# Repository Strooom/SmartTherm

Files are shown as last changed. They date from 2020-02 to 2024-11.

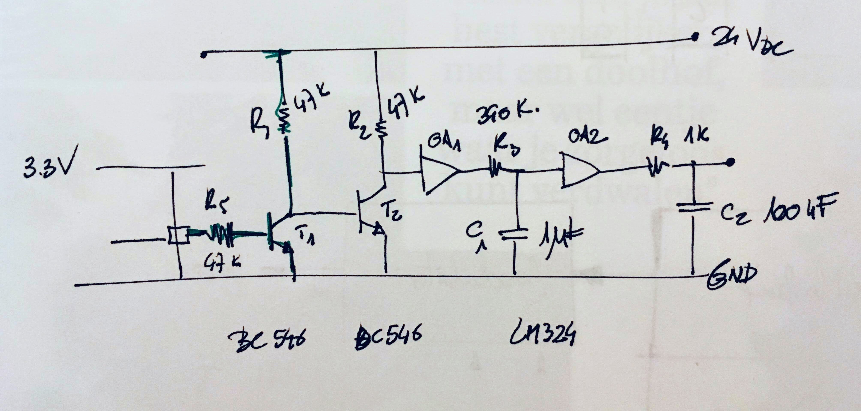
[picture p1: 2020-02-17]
docs/Schematics.JPG

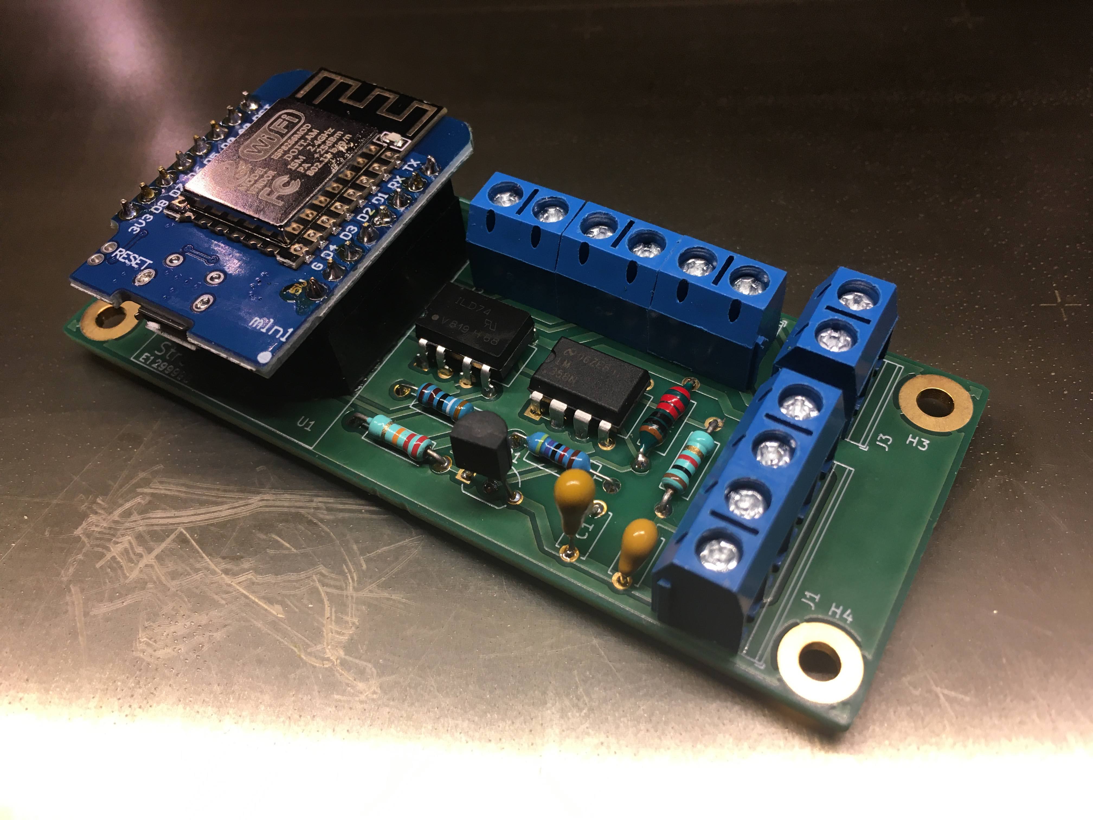
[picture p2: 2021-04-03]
docs/Hardware V2.JPG

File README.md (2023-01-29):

# SmartTherm
Controlling a Junkers heating (Eurostar ZWE24) with an IoT thermostat

* schematics (kiCAD)
* PCB (kiCAD)
* TouchScreen control (Nextion display)
* SmartPhone app (Blynk)
* 3D Printed enclosure (Fusion360)
* Alternative config with ESPHome and Home Assistant

All documentation is in the Wiki : https://github.com/Strooom/SmartTherm/wiki

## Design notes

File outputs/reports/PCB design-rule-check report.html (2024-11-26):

Logo

| DRC report for SmartTherm-PCB
| PCB: SmartTherm-PCB Revision: None Date: 2024-11-26T11:26:57+0000 KiCad Version: 8.0.6 | Errors: 0 Warnings: 0 Total: 0

Generated by KiBot (https://github.com/INTI-CMNB/KiBot/) v1.8.2

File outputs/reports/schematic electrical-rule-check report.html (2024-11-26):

Logo

| ERC report for SmartTherm-PCB
| Schematic: SmartTherm-PCB Revision: V3.0 Date: 2024-11-26T11:26:56+0000 KiCad Version: 8.0.6 | Errors: 0 Warnings: 0 Total: 0

Generated by KiBot (https://github.com/INTI-CMNB/KiBot/) v1.8.2

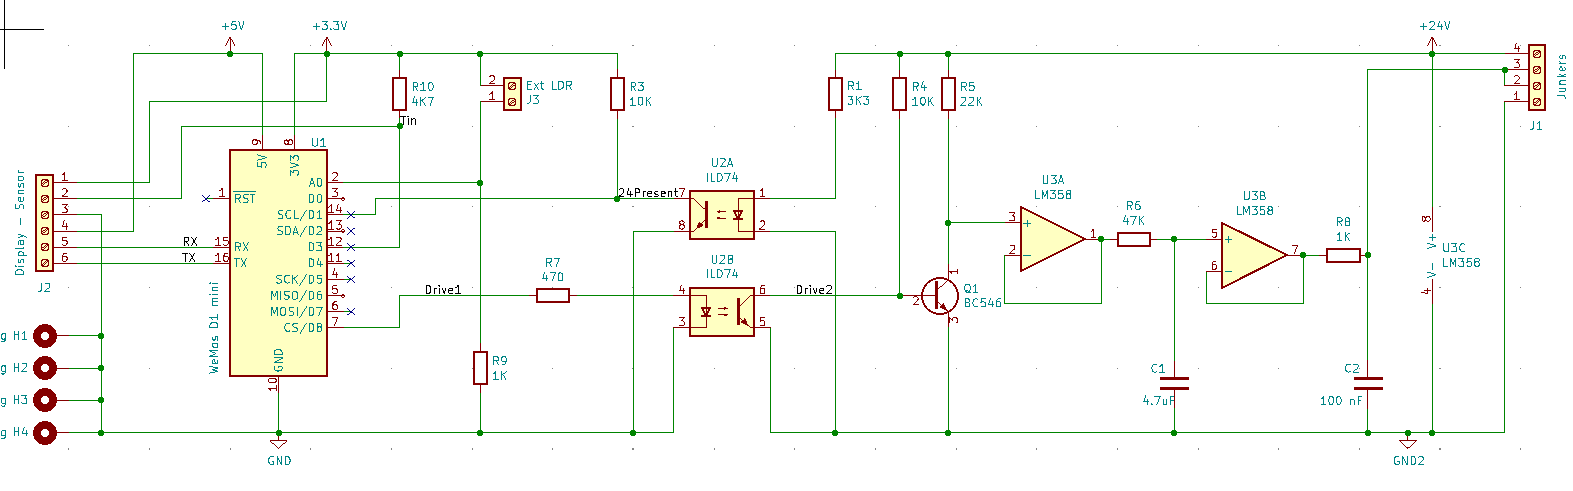
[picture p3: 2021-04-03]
docs/Schematics V2.PNG

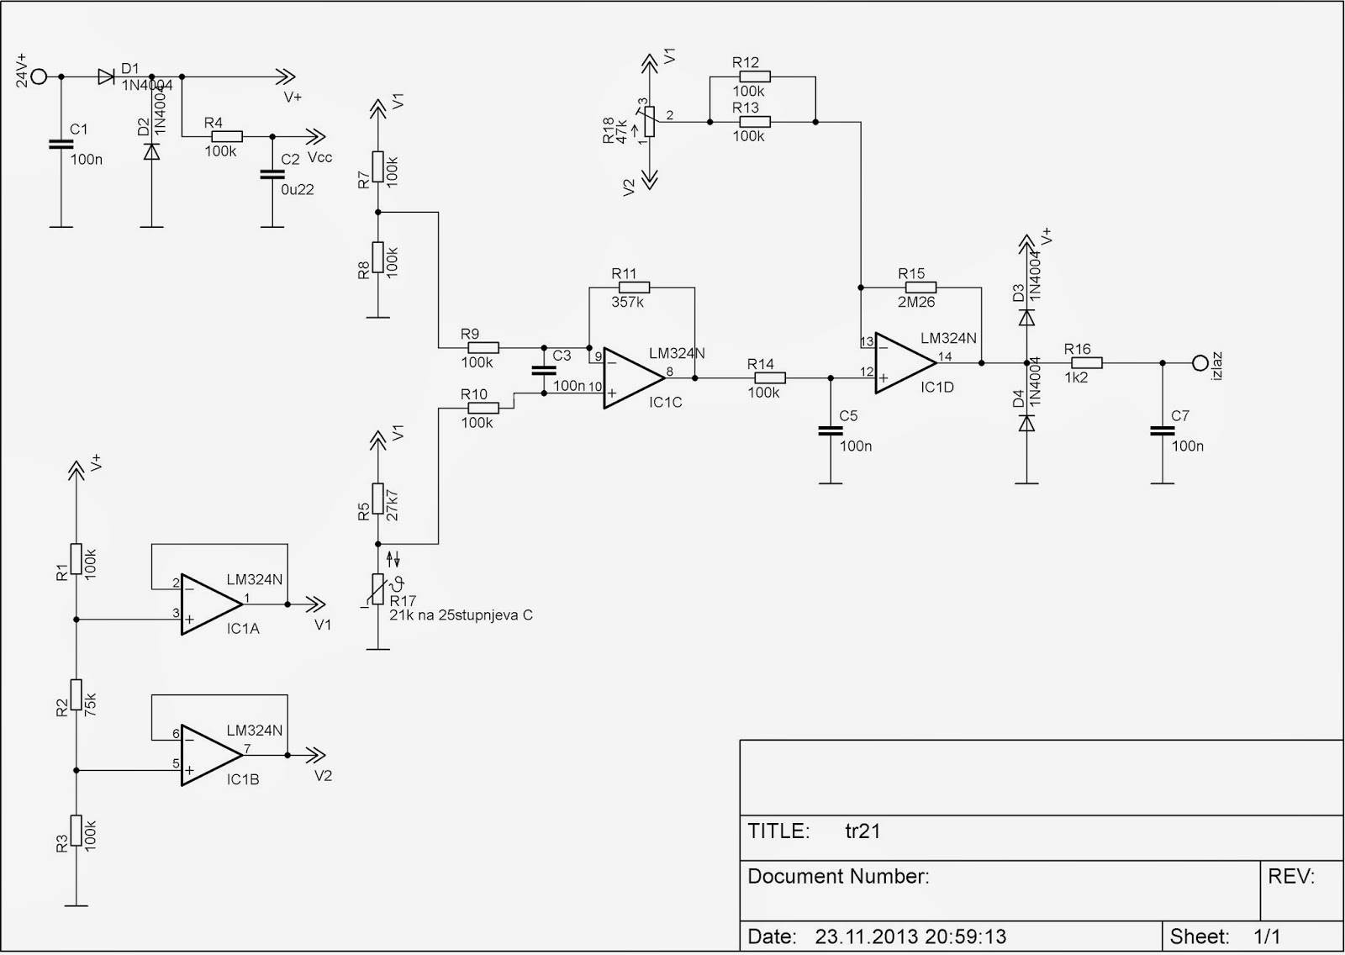
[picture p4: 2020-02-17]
docs/Schematics TR21.jpg

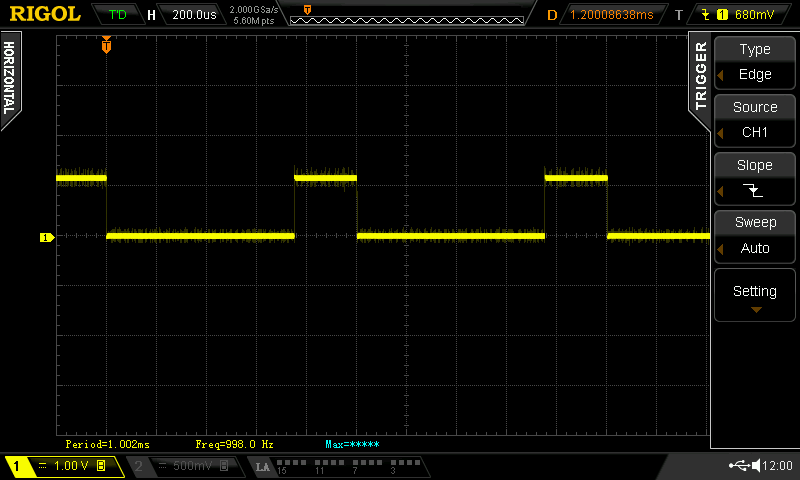
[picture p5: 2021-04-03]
docs/optocoupler input.png

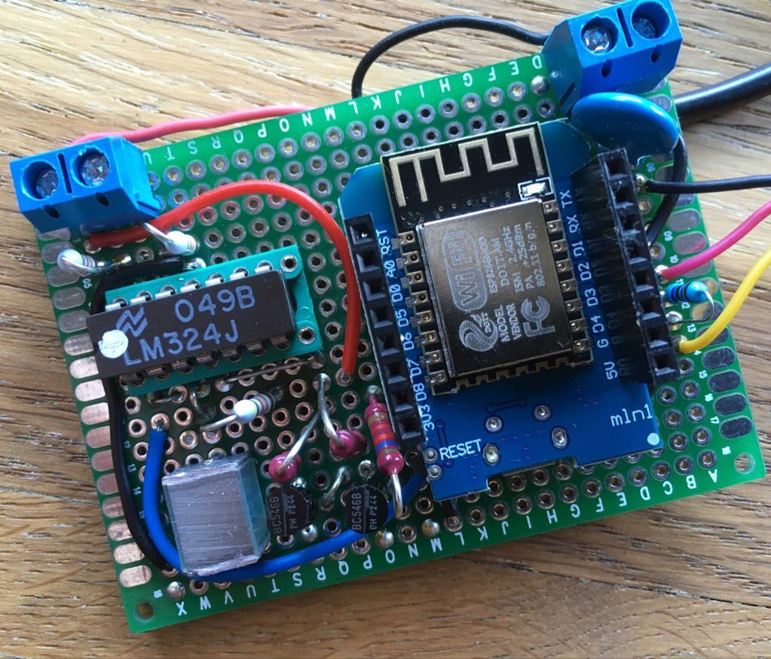
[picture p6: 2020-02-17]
docs/Prototype.JPG

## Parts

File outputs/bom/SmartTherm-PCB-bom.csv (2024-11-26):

Row | Description | Part | References | Value | Footprint | Quantity Per PCB | Status | Datasheet | manufacturerPartNumber | mouserPartNumber
1 |  | C | C2 | 100 nF | C_Disc_D4.7mm_W2.5mm_P5.00mm | 1 |  | https://product.tdk.com/system/files/dam/doc/product/capacitor/ceramic/lead-mlcc/catalog/leadmlcc_halogenfree_fa_en.pdf | FA22X7R2J104KNU06 | 810-FA22X7R2J104KNU6
2 |  | C | C1 | 4.7uF | C_Disc_D4.7mm_W2.5mm_P5.00mm | 1 |  | https://www.mouser.be/datasheet/2/281/1/RCE_X7R_X7S_25V_100V_E-1670872.pdf | RCEC72A475MWM1H03A | 81-RCEC72A475MWM1H3A
3 |  | Screw_Terminal_01x06 | J2 | Display - Sensor | TerminalBlock_Phoenix_PT-1,5-6-5.0-H_1x06_P5.00mm_Horizontal | 1 |  | https://www.phoenixcontact.com/us/products/1730052/pdf | 1730052 | 651-1730052
4 |  | Screw_Terminal_01x02 | J3 | Ext LDR | TerminalBlock_Phoenix_PT-1,5-2-5.0-H_1x02_P5.00mm_Horizontal | 1 |  | https://www.phoenixcontact.com/us/products/1711026/pdf | 1711026 | 651-1711026
5 |  | Screw_Terminal_01x04 | J1 | Junkers | TerminalBlock_Phoenix_PT-1,5-4-5.0-H_1x04_P5.00mm_Horizontal | 1 |  | https://www.phoenixcontact.com/us/products/1711042/pdf | 1711042 | 651-1711042
6 |  | BC546 | Q1 | BC546 | TO-92L_Inline_Wide | 1 |  | https://diotec.com/request/datasheet/bc546.pdf | BC546A | 637-BC546A
7 |  | R | R7 | 470 | R_Axial_DIN0207_L6.3mm_D2.5mm_P10.16mm_Horizontal | 1 |  | https://www.vishay.com/doc?31027 | RL07S471GB14 | 71-RL07S-G-470
8 |  | R | R8 R9 | 1K | R_Axial_DIN0207_L6.3mm_D2.5mm_P10.16mm_Horizontal | 2 |  | https://www.vishay.com/doc?31027 | RL07S102GB14 | 71-RL07S-G-1K
9 |  | R | R1 | 3K3 | R_Axial_DIN0207_L6.3mm_D2.5mm_P10.16mm_Horizontal | 1 |  | https://www.vishay.com/doc?31027 | RL07S332GB14 | 71-RL07S-G-3.3K
10 |  | R | R10 | 4K7 | R_Axial_DIN0207_L6.3mm_D2.5mm_P10.16mm_Horizontal | 1 |  | https://www.vishay.com/doc?31027 | RL07S472GB14 | 71-RL07S-G-4.7K
11 |  | R | R3 R4 | 10K | R_Axial_DIN0207_L6.3mm_D2.5mm_P10.16mm_Horizontal | 2 |  | https://www.vishay.com/doc?31027 | RL07S103GB14 | 71-RL07S-G-10K
12 |  | R | R5 | 22K | R_Axial_DIN0207_L6.3mm_D2.5mm_P10.16mm_Horizontal | 1 |  | https://www.vishay.com/doc?31027 | RL07S223GB14 | 71-RL07S-G-22K
13 |  | R | R6 | 47K | R_Axial_DIN0207_L6.3mm_D2.5mm_P10.16mm_Horizontal | 1 |  | https://www.vishay.com/doc?31027 | RL07S473GB14 | 71-RL07S-G-47K
14 |  | ILD74 | U2 | ILD74 | DIP-8_W7.62mm | 1 |  | https://www.vishay.com/doc?83640 | ILD74 | 782-ILD74
15 |  | LM358 | U3 | LM358 | DIP-8_W7.62mm | 1 |  | https://www.ti.com/lit/gpn/lm358-n | LM358N/NOPB | 926-LM358N/NOPB
16 |  | WeMos_D1_mini | U1 | WeMos D1 mini | WEMOS_D1_mini_light | 1 |  | https://wiki.wemos.cc/products:d1:d1_mini#documentation
Project info:
Schematic: | SmartTherm-PCB
Variant: | default
Revision: | V3.0
Date: | 2024-11-26
KiCad Version: | 8.0.6+1
Statistics:
Component Groups: | 16
Component Count: | 18
Fitted Components: | 18
Number of PCBs: | 1
Total Components: | 18

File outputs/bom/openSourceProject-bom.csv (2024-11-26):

Row | Description | Part | References | Value | Footprint | Quantity Per PCB | Status | Datasheet
1 | Light emitting diode | LED | D1 | LED | LED_0603_1608Metric | 1 |  | ~
2 | Resistor | R | R1 | R | R_0603_1608Metric | 1 |  | ~
Project info:
Schematic: | openSourceProject
Variant: | default
Revision: | V0.9
Date: | Tue Oct 15 12:13:48 2024
KiCad Version: | 8.0.4+1
Statistics:
Component Groups: | 2
Component Count: | 2
Fitted Components: | 2
Number of PCBs: | 1
Total Components: | 2

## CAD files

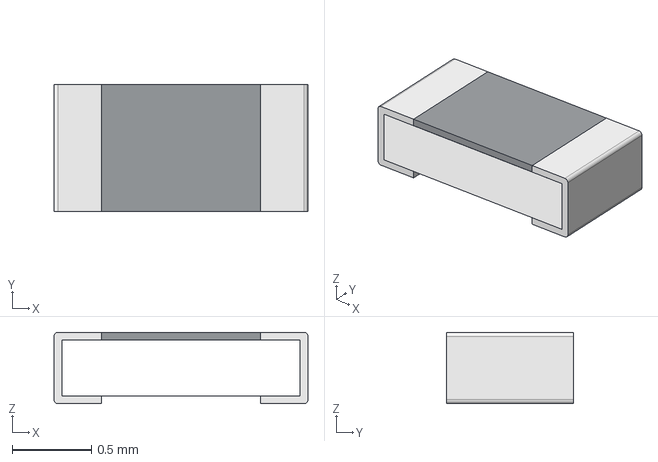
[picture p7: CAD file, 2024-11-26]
inputs/3dmodels/R0603.step
1.60 x 0.8 x 0.45 mm

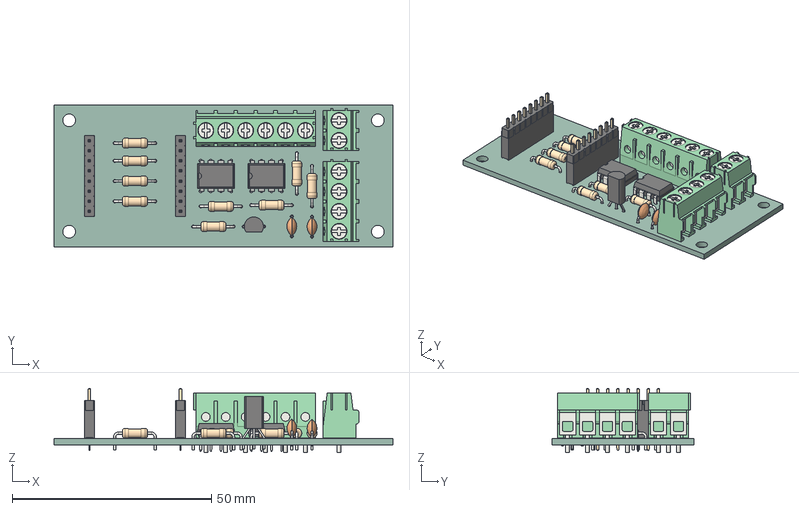
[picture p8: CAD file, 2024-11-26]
outputs/pcb/SmartTherm-PCB-3D.step
85.1 x 35.6 x 16.1 mm
C_Disc_D47mm_W25mm_P500mm x 2
TO-92L_Inline_Wide
R_Axial_DIN0207_L63mm_D25mm_P1016mm_Horizontal x 9
DIP-8_W7.62mm x 2
TerminalBlock_Phoenix_PT_15_2_50_H_1x02_P500mm_Horizontal
TerminalBlock_Phoenix_PT_15_4_50_H_1x04_P500mm_Horizontal
PinHeader_1x08_P254mm_Vertical x 2
PinSocket_1x08_P2.54mm_Vertical x 2
TerminalBlock_Phoenix_PT_15_6_50_H_1x06_P500mm_Horizontal
kibot_mradeprp_PCB

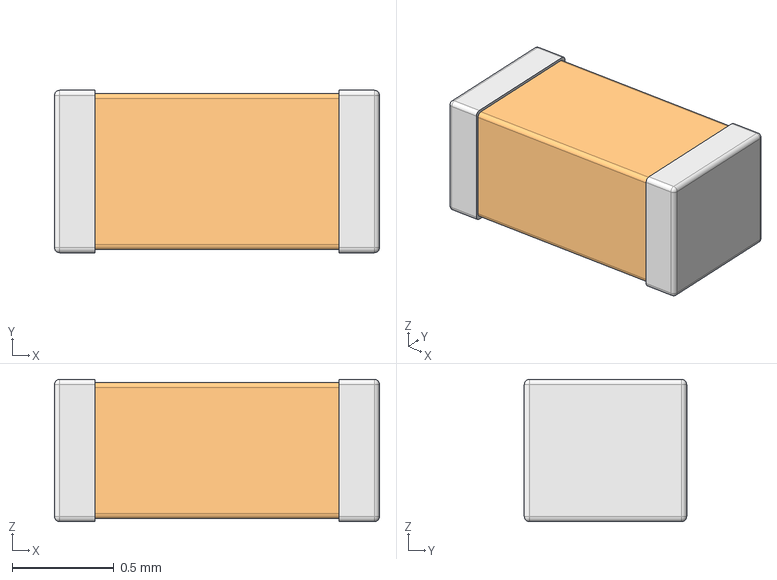
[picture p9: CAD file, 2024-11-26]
inputs/3dmodels/C0603.step
1.60 x 0.8 x 0.7 mm

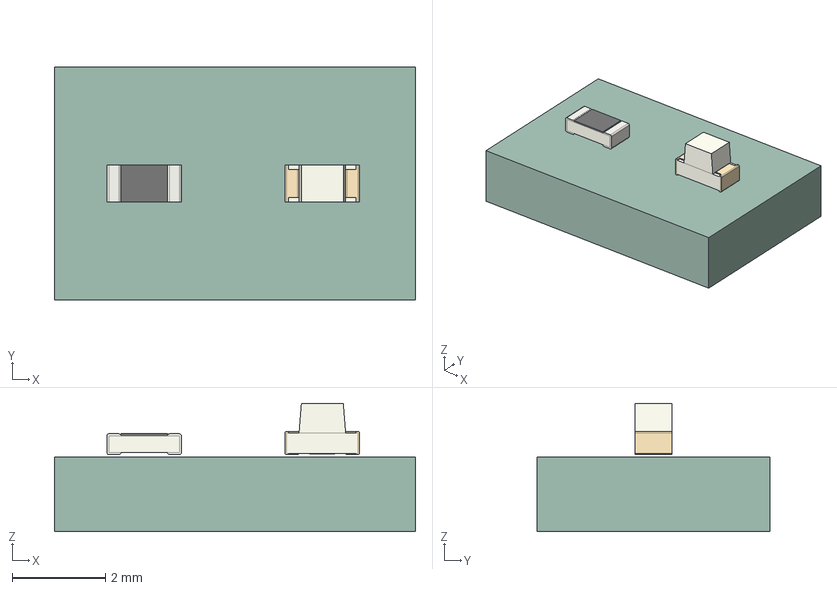
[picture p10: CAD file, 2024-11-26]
outputs/pcb/openSourceProject-3D.step
7.75 x 5.00 x 2.75 mm
LED_0603_1608Metric
R_0603_1608Metric
kibot_kx9a3z6y_PCB

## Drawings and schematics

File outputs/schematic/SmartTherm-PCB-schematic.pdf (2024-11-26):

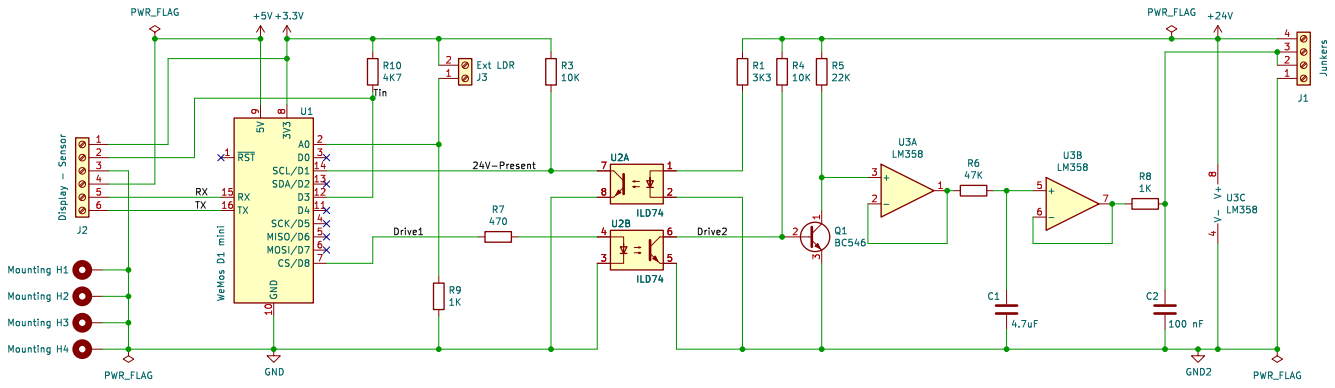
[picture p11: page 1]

File: SmartTherm-PCB.kicad_sch Sheet: / Strooom

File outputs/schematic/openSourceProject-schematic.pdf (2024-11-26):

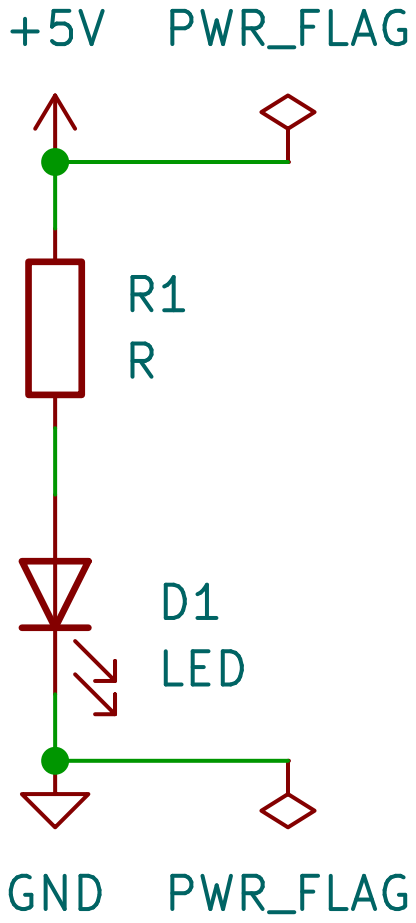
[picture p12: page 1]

Id: 1/1 Title: File: openSourceProject.kicad_sch Sheet: /

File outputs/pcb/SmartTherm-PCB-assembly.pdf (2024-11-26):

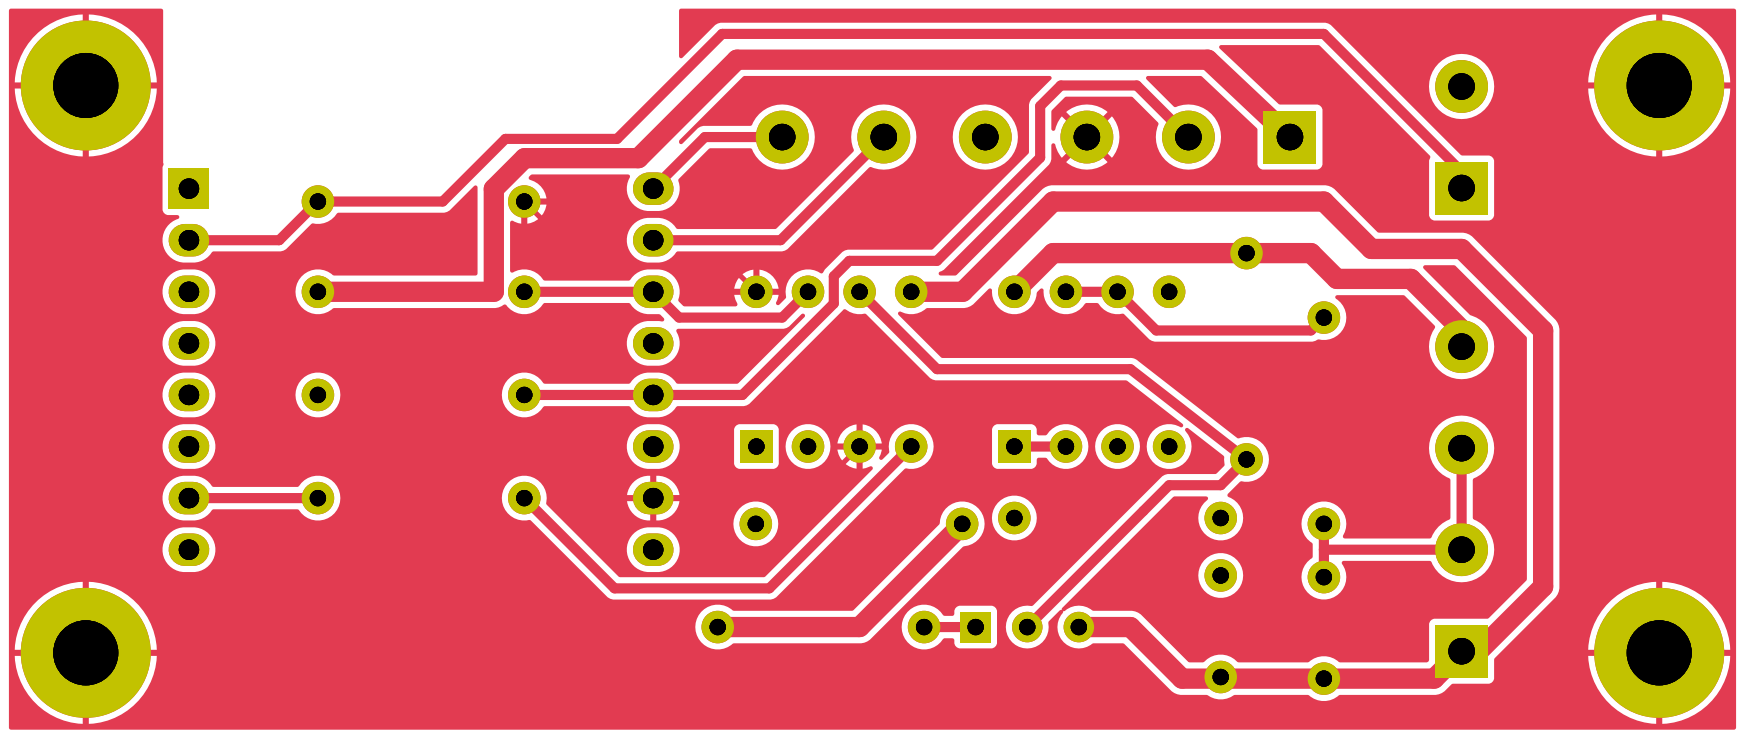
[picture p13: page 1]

U1

R7

SmartTherm V3.0
Strooom.be

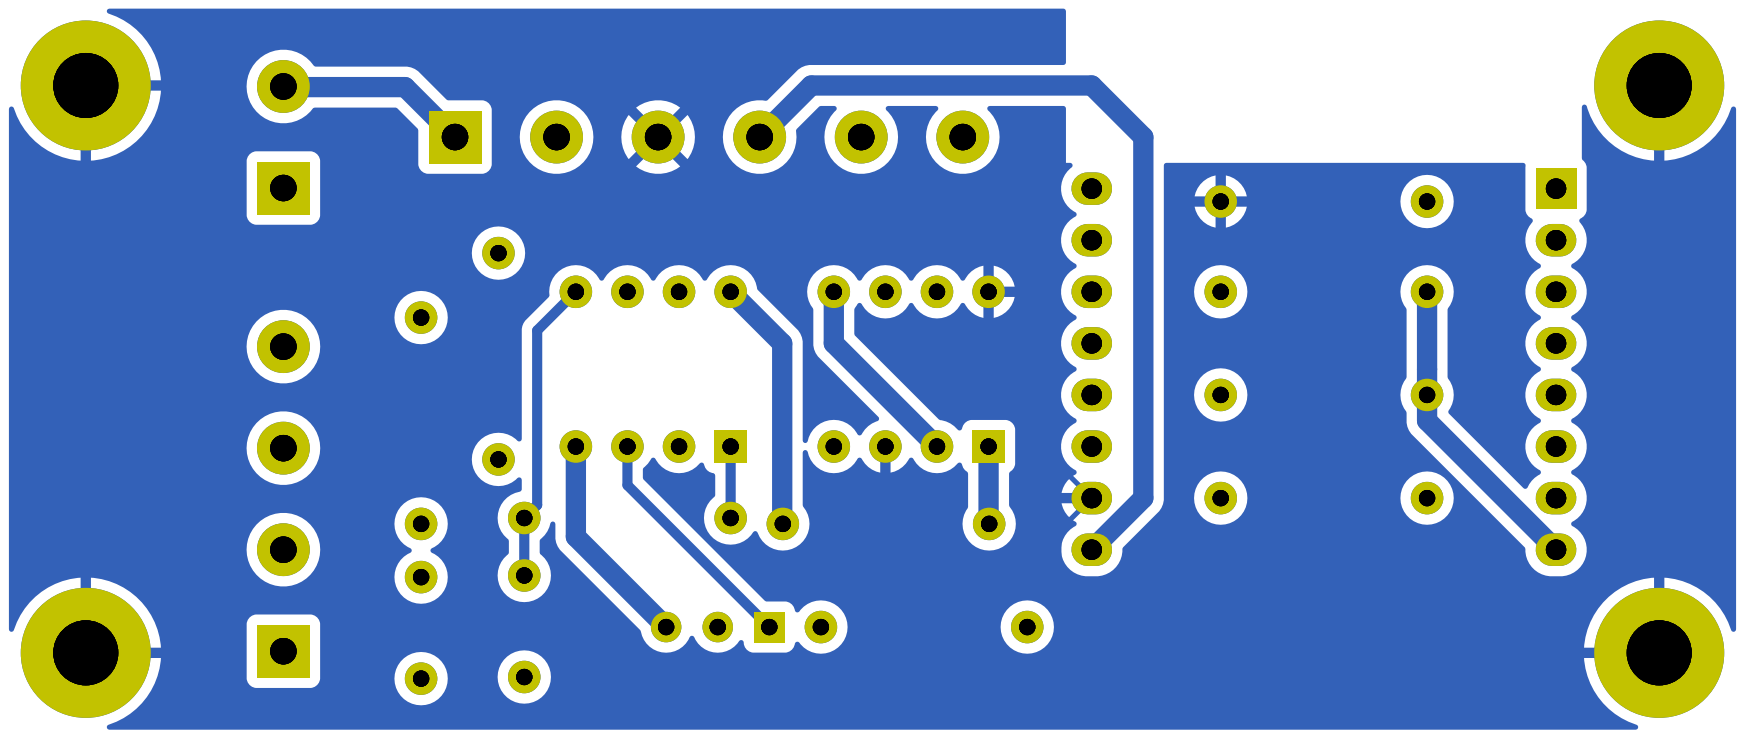
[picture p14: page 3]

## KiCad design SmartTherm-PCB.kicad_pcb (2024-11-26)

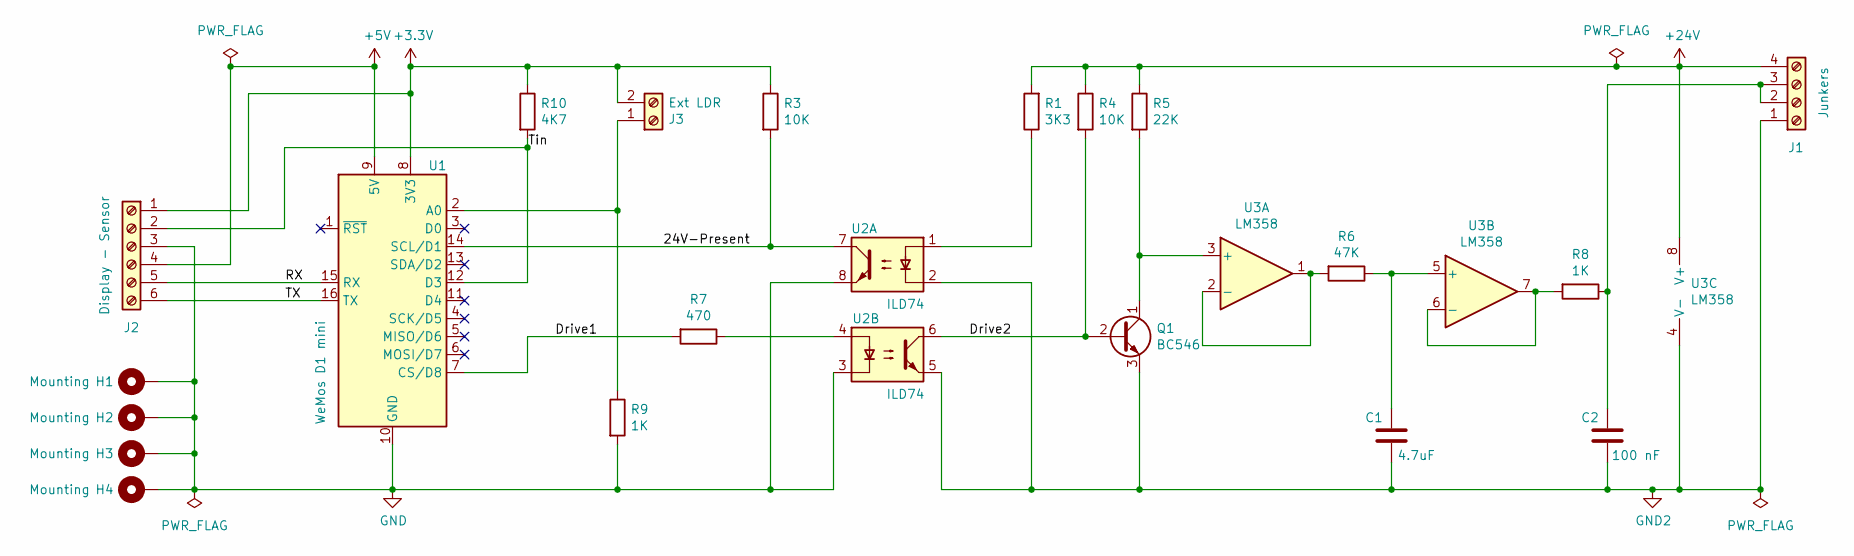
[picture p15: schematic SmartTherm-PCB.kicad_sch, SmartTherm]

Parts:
C1: 4.7uF; C_Disc_D4.7mm_W2.5mm_P5.00mm; manufacturerPartNumber RCEC72A475MWM1H03A; mouserPartNumber 81-RCEC72A475MWM1H3A
C2: 100 nF; C_Disc_D4.7mm_W2.5mm_P5.00mm; manufacturerPartNumber FA22X7R2J104KNU06; mouserPartNumber 810-FA22X7R2J104KNU6
H1, H2, H3, H4: Mounting; MountingHole_3.2mm_M3_Pad; manufacturerPartNumber na; mouserPartNumber na
J1: Junkers; TerminalBlock_Phoenix_PT-1,5-4-5.0-H_1x04_P5.00mm_Horizontal; manufacturerPartNumber 1711042; mouserPartNumber 651-1711042
J2: Display - Sensor; TerminalBlock_Phoenix_PT-1,5-6-5.0-H_1x06_P5.00mm_Horizontal; manufacturerPartNumber 1730052; mouserPartNumber 651-1730052
J3: Ext LDR; TerminalBlock_Phoenix_PT-1,5-2-5.0-H_1x02_P5.00mm_Horizontal; manufacturerPartNumber 1711026; mouserPartNumber 651-1711026
Q1: BC546; TO-92L_Inline_Wide; manufacturerPartNumber BC546A; mouserPartNumber 637-BC546A
R1: 3K3; R_Axial_DIN0207_L6.3mm_D2.5mm_P10.16mm_Horizontal; manufacturerPartNumber RL07S332GB14; mouserPartNumber 71-RL07S-G-3.3K
R3, R4: 10K; R_Axial_DIN0207_L6.3mm_D2.5mm_P10.16mm_Horizontal; manufacturerPartNumber RL07S103GB14; mouserPartNumber 71-RL07S-G-10K
R5: 22K; R_Axial_DIN0207_L6.3mm_D2.5mm_P10.16mm_Horizontal; manufacturerPartNumber RL07S223GB14; mouserPartNumber 71-RL07S-G-22K
R6: 47K; R_Axial_DIN0207_L6.3mm_D2.5mm_P10.16mm_Horizontal; manufacturerPartNumber RL07S473GB14; mouserPartNumber 71-RL07S-G-47K
R7: 470; R_Axial_DIN0207_L6.3mm_D2.5mm_P10.16mm_Horizontal; manufacturerPartNumber RL07S471GB14; mouserPartNumber 71-RL07S-G-470
R8, R9: 1K; R_Axial_DIN0207_L6.3mm_D2.5mm_P10.16mm_Horizontal; manufacturerPartNumber RL07S102GB14; mouserPartNumber 71-RL07S-G-1K
R10: 4K7; R_Axial_DIN0207_L6.3mm_D2.5mm_P10.16mm_Horizontal; manufacturerPartNumber RL07S472GB14; mouserPartNumber 71-RL07S-G-4.7K
U1: WeMos D1 mini; WEMOS_D1_mini_light
U2: ILD74; DIP-8_W7.62mm; manufacturerPartNumber ILD74; mouserPartNumber 782-ILD74
U3: LM358; DIP-8_W7.62mm; manufacturerPartNumber LM358N/NOPB; mouserPartNumber 926-LM358N/NOPB

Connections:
+3.3V: J2.1, J3.2, R3.1, R10.1, U1.8 (3V3)
+5V: J2.4, U1.9 (5V)
+24V: J1.4, R1.2, R4.1, R5.1, U3.8 (V+)
/24V-Present: R3.2, U1.14 (SCL/D1), U2.7
/Drive1: R7.2, U1.7 (CS/D8)
/Drive2: Q1.2 (B), R4.2, U2.6
/RX: J2.5, U1.15 (RX)
/TX: J2.6, U1.16 (TX)
/Tin: J2.2, R10.2, U1.12 (D3)
GND: H1.1, H2.1, H3.1, H4.1, J2.3, R9.2, U1.10 (GND), U2.3, U2.8
GND2: C1.2, C2.2, J1.1, Q1.3 (E), U2.2, U2.5, U3.4 (V-)
unnamed: C2.1, J1.2, J1.3, R8.1
unnamed: J3.1, R9.1, U1.2 (A0)
unnamed: Q1.1 (C), R5.2, U3.3 (+)
unnamed: R1.1, U2.1
unnamed: R7.1, U2.4
unnamed: R6.2, U3.1, U3.2 (-)
unnamed: C1.1, R6.1, U3.5 (+)
unnamed: R8.2, U3.6 (-), U3.7

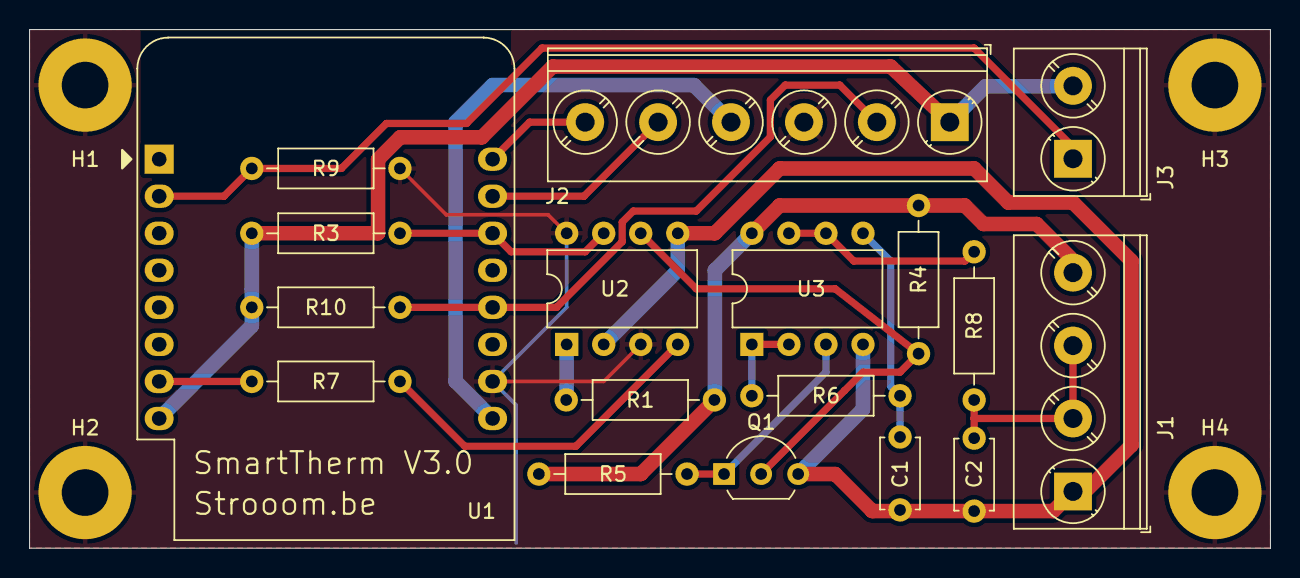
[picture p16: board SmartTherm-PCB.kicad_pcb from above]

Board: 2 copper layers, 85.1 x 35.6 mm, 22 parts (0 on the bottom side), 19 nets.

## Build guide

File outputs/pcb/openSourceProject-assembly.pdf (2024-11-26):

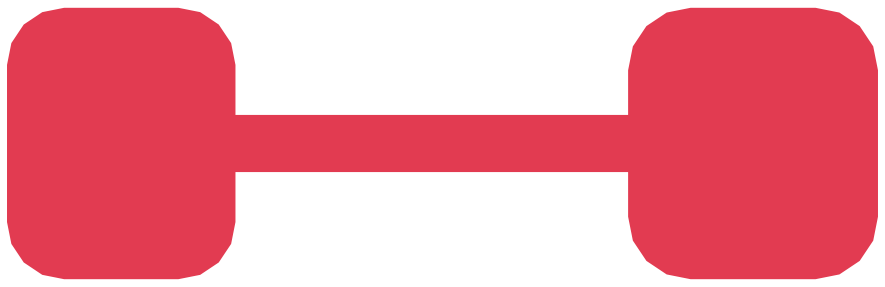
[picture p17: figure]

V0.9

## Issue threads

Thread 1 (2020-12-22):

Pic

mbrevda, 2020-12-22:
Can you possible show a picture of how this is connected to the boiler? Thanks!

Strooom, 2020-12-24:
Pin 1 = 24V
Pin 2 = Control : From thermostat or MCU to Junkers
Pin 4 = Ground

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

mbrevda, 2021-02-23:
Thanks! Ended up going with a Shelly as illustrated [here](https://blog.pattyland.de/2019/12/01/alte-junkers-gastherme-smart-machen/), along with thermostats in every room. I guess that means I'm not utilizing modulation. Wonder what the real-world implications are...

nagyrobi, 2023-11-13:
> Wonder what the real-world implications are...

Less efficiency thus higher energy consumption...

Closed 2020-12-24.

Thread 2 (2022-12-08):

Purchase options?

jkl83, 2022-12-08:
Hi,
I have Eurostar ZWE24 and wanted to control it through home assistant.
Is there any way you can help with that?

Can I buy your thermostat as a complete unit?

Thank you.

renarena, 2022-12-09:
i am also interested

Strooom, 2022-12-13:
Hi, if there would be sufficient demand, I could run a small production. However for 2 units it's not really profitable. Would need to be at least 20.. I'll keep your request in mind for the future.
On the ESP, you could connect MQTT to eg. a nodeRED and then from there you could connect ti to home assistant.

jensweimann, 2023-01-20:
Thank you very much for the work @Strooom!

I built the project recently and have a couple of spare pcbs that I ordered from pcbway. I'll send them inside germany if someone wants it. I can also share the list of components I purchased from an electronics shop.

Also I wrote a small esphome script for home assitant control. I can make a pull request for that if you're interested.

renarena, 2023-01-21:
I am interested. How can i contact you?

niesamowitysmyk, 2023-01-21:
I am intersting too. It is very intersting poject!

jensweimann, 2023-01-21:
Please send me a pm over here: https://community.home-assistant.io/t/control-junkers-gas-heating-1-2-4-interface-with-home-assistant/354658/7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

mtaberna, 2023-01-25:
I would also be interested @jensweimann

jensweimann, 2023-01-28:
See PR: https://github.com/Strooom/SmartTherm/pull/4

niesamowitysmyk, 2023-02-06:
I just launched this solution with my Junkers Eurostar. Everything started up perfectly, including the thermostat in the HA. Thank you very much!
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

Strooom, 2023-02-07:
Nice work!
I am now busy on some other projects (https://github.com/Strooom/MuMo-V2-Node-PCB for HW and https://github.com/Strooom/STM32WLE5x-SX126X-LoRa for the related firmware), so I am not actively working on this SmartTherm project at this time.
Still, it's always nice to read that a maker, somewhere in the world, found your work useful and helpful.
Note that I do have github sponsoring set up : https://github.com/sponsors/Strooom but a simple thank you is also appreciated.

Thank you all, good luck with your builds and have a nice day.

Tylkopoco, 2023-04-02:
> I just launched this solution with my Junkers Eurostar. Everything started up perfectly, including the thermostat in the HA. Thank you very much! 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

Do you have any PCBs left ?

jkl83, 2023-11-15:
Finished creating mine yesterday. Time to launch.
Got pcb from pcbway.com (had to get 5) very cheap as this was my first order.
Got all the components from tme.eu, but you can get those anywhere.

Thank you @Strooom and all other contributors.

nagyrobi, 2023-11-15:
Me too. I plan to sell 3 of them (assembled ready to run), keep one alive and one for spare.

Schnoop, 2023-11-16:
I made a list of the need components at my favourite electronic dealer: https://www.reichelt.de/my/2099518

nagyrobi, 2023-11-16:
Instead of direct screw terminals from the family CTB0502-6, I suggest to use family KFG-2EDGV-5.08-6P + KFG-2EDGK-5.08-6P, as they can be easily plugged/unplugged without having to re-screw cables.

Schnoop, 2023-11-16:
Yeah. Maybe an option. :)

Schnoop, 2023-11-28:
I ordered a few boards. I would give away five of these. Shipping only in Germany. 2.5 EUR via PayPal. The boards are not yet populated with components.

phmllr, 2024-01-30:
I Got 2 Completed PCBs with components sdolderd an 3 PCBs without components for sale if somone interested

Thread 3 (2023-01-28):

MQTT

fir3drag0n, 2023-01-28:
Is there a new firmware for v2 to control it by MQTT?

I would like to integrate it in iobroker.

jensweimann, 2023-01-28:
See PR: https://github.com/Strooom/SmartTherm/pull/4

Strooom, 2023-01-29:
I am currently not working on this project - feel free to build the hardware and put whatever ESP8266 (or even ESP32) software on it. For my application, it is doing its job and I have too many other developments taking up all of my time.

That being said : my original development is using Blynk, but this application has had a complete makeover, so the one I am using is obsolete. So, some day I could rewrite the software to work with some other cloud solution, eg the Arduino cloud.

Any developers interested on taking the development further : I can add you to the team and then you can take ownership.

Thank you all!

Closed 2023-01-29.

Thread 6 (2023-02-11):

add to description, how to connect  J1 to Junkers 1-2-4 interface

renarena, 2023-02-11:
Please, can you add the junkers 1-2-4 contacts in https://github.com/Strooom/SmartTherm/blob/master/hardware/SmartTherm-v2-schematics.pdf or add a note in the docs
to show J1 contacts 1 2 3 4 does not correspond to Junkers 1-2-4?

J1-1 = GND = Junkers 4
J1-4 = +24V = Junkers 1

Strooom, 2023-02-20:
You are right - it would have been better if the numbering on the SmartTherm connector was matching the numbering on the Junkers boilers. I will correct that in the next version.

In the mean time, here are the correct pin numberings on both sides:
Junkers 1 = 24V = SmartTherm 4
Junkers 2 = drive signal = SmartTherm 2 & 3
Junkers 4 = GND = SmartTherm 1

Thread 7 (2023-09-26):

junkers ZWB 24-1 DE

heapxor, 2023-09-26:
Hello there,
 I am also interested in that solution (reason why - https://community.home-assistant.io/t/bosch-gas-condensing-compact-heating-center-how-to-control-the-flat-heating).

Is that solution still working fine? Do i need to create a PCB by myself?

I am not sure what's 1-2-4 interface, my Junker heater comes with some PCB interface, where original CR 100 thermostat is plugged, i think its 24V circuit using modulation?

Also is there some extension to that solution with a valves, ie. each room separate thermostat (to capture temp) and its valve that is controlled by solution?

Appreciate your help!
Thanks for a great project.

niesamowitysmyk, 2023-09-26:
This solution works perfectly.
In project you can find pcb project files and place order for example in "pcbway" or others provider.
For control external rooms you need to find other independent solution - for example smart valves

heapxor, 2023-09-29:
@niesamowitysmyk thank you for the confirmation.
I do still miss the high level picture...

That project controls the heater using modulation. Assuming the pcb has its own temperature sensor?
So in case i want to extend solution to be able to read temp in multiple rooms and control temp in different rooms using electrical valves i somehow needs to - redesign it?

Maybe i am wrong and that project doesn't act like a room temp meter, and we need to send Temperature data to it ... ie it only turn on/off heater using modulation based on the input temperature value.

thanks

Strooom, 2023-09-29:
A DS18B20 temperature sensor is to be connected to the board. This is where the software gets the temperature. This kind of sensor allows several sensors to be connected to the same bus. But the maximal length of the wires is about 1 meter, so not enough to run to different rooms.

This design was never intended for controlling multiple rooms, and I think it would be too far off to adjust or tweak it.

nagyrobi, 2023-10-17:
I run about 25 DS18B20 sensor all around the house + one out in the yard at 50m distance. They are all connected in parallel, using a 1k resistor as pullup. Works flawlessly.

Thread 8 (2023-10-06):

esphome - smarttherm_power_level // and parallel use

phmllr, 2023-10-06:
esphome:
as seen in your esphome HomeAssistant integration there is an slider for configure the power level. This power level has to bee configured manually, right? So if there are 10°C in my room and i want it to be 20° i should make it to 100% until i reached the 20°C in x-minutes. But if the power level is only put to 50% it would need 2 times as long as on 100%. Did i understand that correctly?

Parallel use:
in some other projects i've seen some schematics with an diode put on the "Junkers 2" or on the J1-2&3 in your yousecase. The diode is for an parallel use of the original Junkers thermostat as backup in case of an broken esp or smotething else. is it possible to put the diodes in your schematics too? I would do by my self but i want t know if its possible with your hardware.

nagyrobi, 2023-11-04:
Have a look at the [PID Thermostat](https://esphome.io/components/climate/pid.html), which continuously adjusts the "slider" to keep temperature in your house.

jensweimann, 2023-11-15:
Personally on my setup the slider is controlled by home assistant automation, based on the delta between current temperature and target temperature. You can decide that way yourself what the appropriate power level is.

I came to the conclusion that its more economical to run the burner on minimal power for longer if possible.

nagyrobi, 2023-11-15:
@jensweimann what's the percentage of your burner during this minimal period? (I use bbqees's hardware to query boiler parameters).

jensweimann, 2023-11-15:
> @jensweimann what's the percentage of your burner during this minimal period? (I use bbqees's hardware to query boiler parameters).

I don't know about this hardware. I just set the slider to 1% which results in the minimal voltage that my burner accepts for powering on (8V).

> Is the automation you use the same as the one in this repo? I tested it, and find the power level calculated from the delta too small to heat up the house.

Yes. Well I guess the usage varies quite a bit for everyone so there is no right and wrong. We can only provide examples. Maybe you can also provide your solution with the PID Thermostat?

nagyrobi, 2023-11-15:
Does your heater have a small glass window you can peek in to see the gas burning? Do yo see the flame sizes? How big are they (maybe you can take a photo)?

My heater is a Junkers Ceraclass Excellence ZSC 28-3 MFA E 23, and it seems that this unit has a wider control range than your suggested 8V-15V interval. I created a config now for the node so I can drag the slider and monitor more precisely the PWM value which generates the voltage which turns on the heating.

Originally, this heater was controlled by a simple on/off relay thermostat, connected to `LR` and `Ls` terminals of the board. I see everywhere, where they control it with either bus or 1/2/4 method that these terminals are shorted with a jumper - I have to investigate what happens when the voltage generated by smarttherm goes to 0 (as if it wouldn't be connected). Because if I disconnect it now, the heater turns on, as it thinks that the on/off thermostat at `LR` and `Ls` demands for heating.

jensweimann, 2023-11-15:
> Does your heater have a small glass window you can peek in to see the gas burning? Do yo see the flame sizes? How big are they at your minimum setting (maybe you can take a photo)? To compare with mine.
No window.. It's a ZWN 18-6

> My heater is a Junkers Ceraclass Excellence ZSC 28-3 MFA E 23, and it seems that this unit has a wider control range than your suggested 8V-15V interval.

I would rather use the new digital control with HT3 with your unit: [EMS-ESP](https://github.com/emsesp/EMS-ESP)
Mine doesn't support the HT3 bus.

nagyrobi, 2023-11-15:
> I don't know about this hardware.

The [EMS bus Wi-Fi Gateway](https://bbqkees-electronics.nl/wiki/gateway/introduction.html) is an ESP32-based device, which runs the [EMS32-ESP](https://github.com/emsesp/EMS-ESP32) firmware and connects to the Junkers bus terminals (`B` `B`). The firmware connects to MQTT and integrates with various other systems. Some heater configurations although the have the bus onboard, don't support changing certain values - you don't know that until you get the hardware and try it out. That's why I end up modulating by 1/2/4 connection and monitor data through the B/B bus connection. It spits out literally tens of parameters from the heater, like burner power percentage, etc.

nagyrobi, 2023-11-15:
> I would rather use the new digital control with HT3

Two thinks I don't like about EMS32-ESP:
- only supports MQTT, and floods it with a lot of data. operation is not really stable and the developer often makes breaking changes from one release to the other
- I can't turn on/off or modulate remotely the heating of my configuration which is a ZSC 28-3 MFA + FW200 as energy management controller (not thermostat).

nagyrobi, 2023-11-16:
> Maybe you can also provide your solution with the PID Thermostat?

The PID thermostat description is ESPHome docs site is pretty good. The only difficulty which can arise is to calibrate the system with autotune, which is hard to accomplish because a heating system is typically very slow (especially floor heating) and outdoor temperature variations can have higher influence on the results based on the heat retention capacity of the building (eg is it made of concrete, wood, how big windows are, is there thermal insulation on the walls etc).

Instead, I've just set up a simple generic ON/OFF thermostat in HA without PID, and watched temperature oscillations throughout a a few days, maybe a week (chose a fixed setpoint) like this:
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

With this measurement, PID parameters can be calculated manually, I used the description [presented here](https://github.com/ScratMan/HASmartThermostat/discussions/21#discussioncomment-1709437).
Made an spreadsheet to ease the calculations: [PID_calculator_spreadsheet.ods](https://github.com/Strooom/SmartTherm/files/13376050/PID_calculator_spreadsheet.ods), you can start experimenting with the Kp, Ki, Kd values from there. For a heating system, usually the ziegler-nichols algorithm fits the best.

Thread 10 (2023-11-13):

LDR purpose and value/type

nagyrobi, 2023-11-13:
What's the purpose of `Ext LDR` in the schematic (light sensor maybe) and what is the exact type of component to be used?

Strooom, 2023-11-13:
You can connect a light sensor, so the SW could detect day / night from this.
Sensor is something like this : https://www.gotron.be/ldr-photoresistor-100mw-50-160kohm.html
I have never implemented this so I do not have an exact type but it's basically a voltage divider, reading it it via the ADC to determine how much light there is.

nagyrobi, 2023-11-13:
Ok, so a photoresistor of 50-160 kOhm is what was intended to be used?

jensweimann, 2023-11-15:
Yes, this will do. I have a similiar one working on the esphome config.

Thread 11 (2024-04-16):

Is this also compatible with 1-2-4-6 Junkers heaters?

ltctceplrm, 2024-04-16:
Like the TOP 30/375-2 ZBS

Strooom, 2024-04-16:
Mmmm, I don't know this heater.. as it's 4 wires, it looks like it's using a different protocol or interface.
We need to know more info about what is on these 1-2-4-6 wires.

ltctceplrm, 2024-04-16:
1 is for power
2 is a CAN Bus High
4 is ground
6 is CAN Bus Low
The thermostat is a TA270 with this wiring
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
And this is what the wiring in the heater looks like:
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

nagyrobi, 2024-04-17:
CAN Bus is a completely different type of animal...

Strooom, 2024-04-18:
Indeed, my design is intended for the older 'analog' thermostat interface. I have never used an ESP32 with CAN, but it seems the MCU has this interface.
So you could modify the design (hardware ánd software) to make it work for a heater with CAN.
Biggest challenge will be to find out what messages/protocol to talk to the heater.

nagyrobi, 2024-04-18:
But, given the fact that the heater has the connector labelled as **1-2-4**-6, there are chances that you can use the analog solution provided by this hardware on the 1-2-4 pins only. You have to check in the service/installer manual of your heater, if the communication protocol of the heater can be switched from CAN 1-2-4-6 to 0-24V 1-2-4.
In my case (a Junkers Ceraclass) it was possible to choose between EMS and 0-24V 1-2-4. Of course the original thermostat won't work in this case.

ltctceplrm, 2024-04-18:
>  So you could modify the design (hardware ánd software) to make it work for a heater with CAN.
Biggest challenge will be to find out what messages/protocol to talk to the heater.

I think that would be well above my skill level unfortunately, especially because I don't know how long my heater will still last. Next one I'll definitely find one that is compatible with every smart system possible 😉

> Interesting that Junkers/Bosch used EMS protocol (proprietary interface) so far, since when they switched to CAN?

My heater (Junkers TOP 30/375-2 ZBS) uses Heatronic 2 and I think EMS is Heatronic 3-4 right? I think my model might be too old then perhaps.

> But, given the fact that the heater has the connector labelled as **1-2-4**-6, there are chances that you can use the analog solution provided by this hardware on the 1-2-4 pins only. You have to check in the service/installer manual of your heater, if the communication protocol of the heater can be switched from CAN 1-2-4-6 to 0-24V 1-2-4. In my case (a Junkers Ceraclass) it was possible to choose between EMS and 0-24V 1-2-4. Of course the original thermostat won't work in this case.

That would be very interesting but will it still support modulation?

nagyrobi, 2024-04-18:
The modulation is done by this circuit!

ltctceplrm, 2024-04-19:
I looked at the manual for the heater and not the thermostat and they do mention that there are two ways of connecting a thermostat, one of them is for the TR-100 with the 1-2-4 cables and the other is with for the TA-270 with the cables like I have.
Here's an image from the manual
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

If I understand correctly I could just unplug the cables going to the green section on the right and instead connect the smarttherm board to the white section on the left, with cables 1-2-4:
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

Strooom, 2024-04-20:
Yes, the manual also mentions the TR21 and this was the thermostat that I reverse engineered and for which the hardware is providing compatible signals.

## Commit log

2020-04-19 Added a Nextion display
    moved OTA code from loop() to separate functions
    added a Nextion display, which for the time being is only displaying temperature and time. Reading buttons will be added later
2021-04-03 add hardware schematics and pcb
    [SmartTherm.kicad_pcb, SmartTherm.sch]
2023-01-28 Add gerber files and a pdf with the list of components
2024-11-26 reorganize repository for workflow
    [C0603.step, R0603.step, SmartTherm-PCB.kicad_pcb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]
2024-11-26 update BOM
    [SmartTherm-PCB.kicad_pcb, SmartTherm-PCB.kicad_sch, SmartTherm-PCB.sch]
2024-11-26 updates to pass ERC/DRC
    [SmartTherm-PCB.kicad_pcb, SmartTherm-PCB.kicad_sch]
2024-11-26 add workflow generated files
    [SmartTherm-PCB-3D.step, SmartTherm-PCB-bom.csv]
